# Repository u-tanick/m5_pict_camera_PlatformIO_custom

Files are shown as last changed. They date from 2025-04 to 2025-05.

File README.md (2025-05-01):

# m5_pict_camera_PlatformIO_custom

Yuikawa-Akiraさんが[こちらで公開されているPict_Cameraのコード](https://gist.github.com/Yuikawa-Akira)をもとに、PlatformIO化＋自分の手持ちの機器に合わせた改修＋機能追加を行ったものです。

オリジナルのピクセルアート風の画像を保存する機能に加えて、以下の機能を追加実装しています。

- スクロールユニットによるカメラシャッター機能
  - オリジナルはエンコーダーユニットですが、スクロールユニットに変更しています。
- デジタルズーム機能（1.0～4.0倍）
  - カメラ撮影モードの際に、スクロールユニットを右に回転させるとズームします。
  - ズームした状態でスクロールユニットを押すとズームされた状態の画像でピクセルアート画像が保存されます。
- プレビューモード機能
  - カメラモードで左にスクロールすると画面が「Press Button Previre Mode」と表示されるのでそこでスクロールユニットを押すと撮像した画像をLCDディスプレイでプレビューする機能に切り替わります。
  - プレビューモード時に再度スクロールユニットを押すとカメラモードに戻ります。
  - プレビューモードに切り替わる際は、その時点の画像のリストを作成するため数秒の処理待ちが発生します。
  - また、画像のIDは電源のON/OFFでリセットされるため必ずしも新しいもの順といった規則性のある順序にはなっていません。

以下の機器をセットする想定で作成したカメラケースのデータを、stlフォルダに格納しています。

- [AtomS3Rカメラ](https://www.switch-science.com/products/9916)
- [ATOMIC TFカードリーダー](https://www.switch-science.com/products/9423)
- [LCDディスプレイユニット](https://www.switch-science.com/products/7358)
- [スクロールユニット](https://www.switch-science.com/products/9917)
- [拡張ハブユニット](https://www.switch-science.com/products/5696)
- [GROVE互換ケーブル 10cm](https://www.switch-science.com/products/5213)
  - 1本
- [GROVE互換ケーブル 5cm](https://www.switch-science.com/products/8664)
  - 2本
- [SDカード Class10 16GB以下](https://www.yodobashi.com/?spcs=Specvaluecode_500000301004005003,500000301004005005_0001_0000000025_0000033030&spcs=Specvaluecode_500000301004005003,500000301004005005_0001_0000000338_0000009621&word=SD%E3%82%AB%E3%83%BC%E3%83%89+16GB)
- [レゴテクニック　ピン](https://www.amazon.co.jp/dp/B07B9R4J55/)
  - 1本
- [モバイルバッテリー：cheero canvas 3200mAh](https://www.amazon.co.jp/dp/B0BPC5BPVK/)
- [USB Type-Cケーブル 10cm以下](https://www.amazon.co.jp/dp/B0DJ85RLDN/)
  - 両端 Type-C のものはなぜか通電しなかったので、Type-A - Type-C を使用しました。
  - あまり10cm以下の商品は少ないのですが、購入の際はご注意（自己責任）ください。
- [100均で売っている 木ネジ（12mm*3mm）](https://jp.daisonet.com/products/4991203166913)

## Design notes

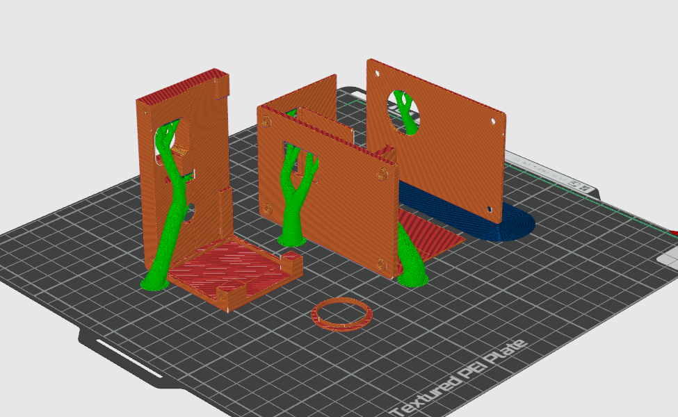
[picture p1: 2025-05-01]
stl/camera-case-set-slice.png

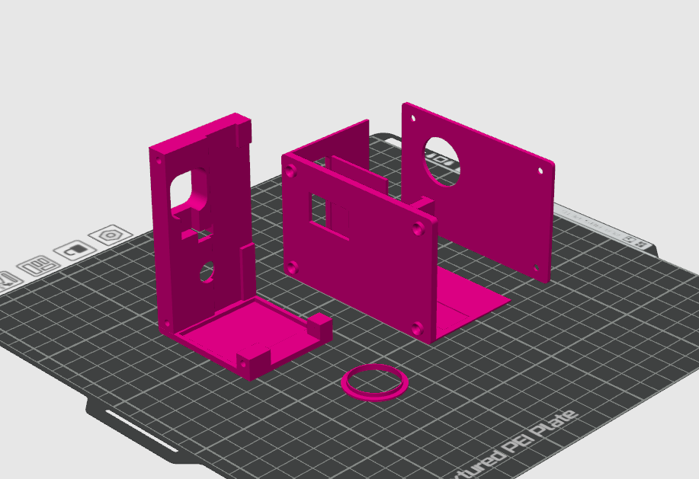
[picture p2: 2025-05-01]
stl/camera-case-set.png

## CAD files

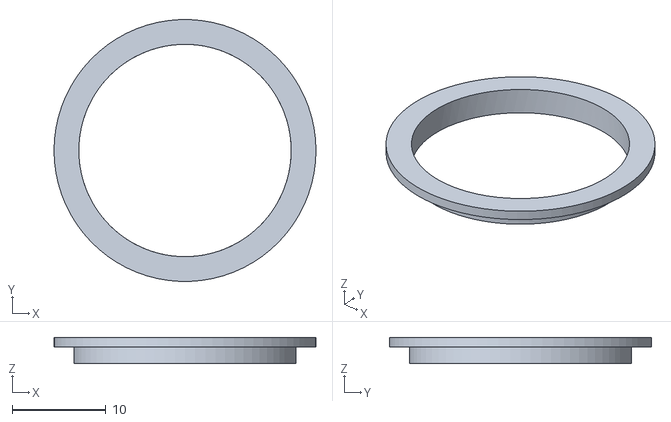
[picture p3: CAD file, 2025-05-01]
stl/camera-case-04_ring v67.stl
28.0 x 28.0 x 2.80

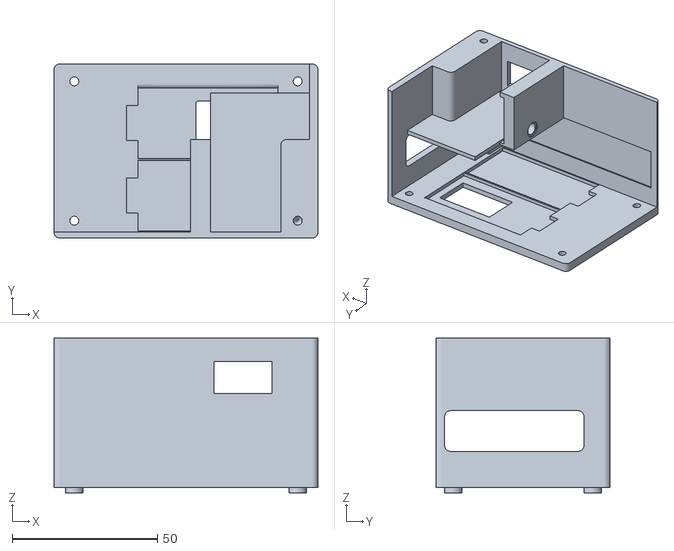
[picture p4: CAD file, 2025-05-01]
stl/camera-case-02_back_bottom_leftpanel v70.stl
91.0 x 60.0 x 53.3

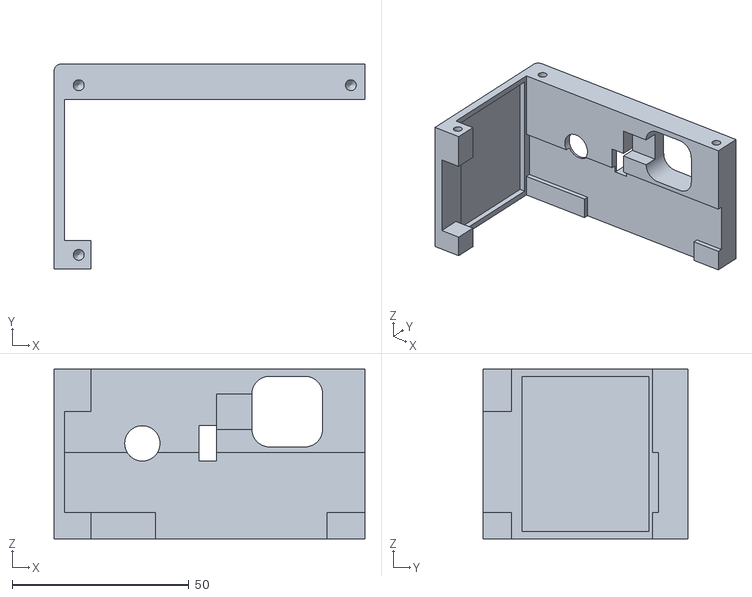
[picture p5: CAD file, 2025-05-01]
stl/camera-case-01_top_rightpanel v71.stl
88.0 x 58.0 x 48.0

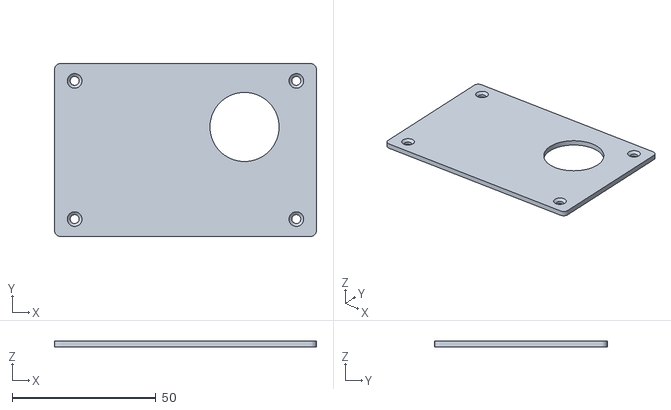
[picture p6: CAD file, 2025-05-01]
stl/camera-case-03_frontpanel v67.stl
91.0 x 60.0 x 2.00

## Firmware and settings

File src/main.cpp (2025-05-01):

#include <M5Unified.h>
#include "M5UnitScroll.h"
#include <M5UnitLCD.h>
#include <esp_camera.h>
#include <SPI.h>
#include <SD.h>
#include <vector>

// ----------------------------------------------------
// Grove PIN
#define PIN_SCL 1
#define PIN_SDA 2

// ----------------------------------------------------
// ユニットスクロール関連の変数・定数
M5UnitScroll scroll;
bool PRESSED_FLG = false;

// ----------------------------------------------------
// UnitLCD関連の変数・定数
M5UnitLCD display;
M5Canvas canvas(&display);

// ----------------------------------------------------
// 最大8色のカラーパレット デフォルト関連の変数・定数
int maxPaletteSize = 8;
uint32_t ColorPalettes[8][8] = {
    {// パレット0 slso8
     0x0D2B45, 0x203C56, 0x544E68, 0x8D697A, 0xD08159, 0xFFAA5E, 0xFFD4A3, 0xFFECD6},
    {// パレット1 都市伝説解体センター風
     0x000000, 0x000B22, 0x112B43, 0x437290, 0x437290, 0xE0D8D1, 0xE0D8D1, 0xFFFFFF},
    {// パレット2 ファミレスを享受せよ風
     0x010101, 0x33669F, 0x33669F, 0x33669F, 0x498DB7, 0x498DB7, 0xFBE379, 0xFBE379},
    {// パレット3 gothic-bit
     0x0E0E12, 0x1A1A24, 0x333346, 0x535373, 0x8080A4, 0xA6A6BF, 0xC1C1D2, 0xE6E6EC},
    {// パレット4 noire-truth
     0x1E1C32, 0x1E1C32, 0x1E1C32, 0x1E1C32, 0xC6BAAC, 0xC6BAAC, 0xC6BAAC, 0xC6BAAC},
    {// パレット5 2BIT DEMIBOY
     0x252525, 0x252525, 0x4B564D, 0x4B564D, 0x9AA57C, 0x9AA57C, 0xE0E9C4, 0xE0E9C4},
    {// パレット6 deep-maze
     0x001D2A, 0x085562, 0x009A98, 0x00BE91, 0x38D88E, 0x9AF089, 0xF2FF66, 0xF2FF66},
    {// パレット7 night-rain
     0x000000, 0x012036, 0x3A7BAA, 0x7D8FAE, 0xA1B4C1, 0xF0B9B9, 0xFFD159, 0xFFFFFF},
};

// カラーパレット値確認(デバッグ用、シリアル出力のみ)
void checkPalettes()
{
  for (int pi = 0; pi < maxPaletteSize; ++pi)
  {
    Serial.printf("%X,%X,%X,%X,%X,%X,%X,%X\n", ColorPalettes[pi][0], ColorPalettes[pi][1], ColorPalettes[pi][2], ColorPalettes[pi][3], ColorPalettes[pi][4], ColorPalettes[pi][5], ColorPalettes[pi][6], ColorPalettes[pi][7]);
  }
}

// ----------------------------------------------------
// カメラ・PSRAM関連の変数・定数
#define POWER_GPIO_NUM 18
camera_fb_t *fb;
camera_config_t camera_config = {
    .pin_pwdn = -1,
    .pin_reset = -1,
    .pin_xclk = 21,
    .pin_sscb_sda = 12,
    .pin_sscb_scl = 9,
    .pin_d7 = 13,
    .pin_d6 = 11,
    .pin_d5 = 17,
    .pin_d4 = 4,
    .pin_d3 = 48,
    .pin_d2 = 46,
    .pin_d1 = 42,
    .pin_d0 = 3,

    .pin_vsync = 10,
    .pin_href = 14,
    .pin_pclk = 40,

    .xclk_freq_hz = 20000000,
    .ledc_timer = LEDC_TIMER_0,
    .ledc_channel = LEDC_CHANNEL_0,

    .pixel_format = PIXFORMAT_RGB565,
    .frame_size = FRAMESIZE_HQVGA,
    // FRAMESIZE_96X96,    // 96x96
    // FRAMESIZE_QQVGA,    // 160x120
    // FRAMESIZE_QCIF,     // 176x144
    // FRAMESIZE_HQVGA,    // 240x176
    // FRAMESIZE_240X240,  // 240x240
    // FRAMESIZE_QVGA,     // 320x240

    .jpeg_quality = 0,
    .fb_count = 2,
    .fb_location = CAMERA_FB_IN_PSRAM,
    .grab_mode = CAMERA_GRAB_LATEST,
    .sccb_i2c_port = 0,
};

// ----------------------------------------------------
// カメラ画像保存関連の変数・定数
char filename_bmp[64];         // SDカード保存ファイル名
int filecounter = 1;           // ファイルカウンターは電源を入れるたびにリセットされる　極稀にファイル名が被るかも
int selectedPalettelndex = -1; // 選択したパレットの番号（0-8：個別指定, -1：未指定（デフォルト））
uint8_t graydata[240 * 176];   // 輝度情報保存
uint32_t btnOnTime = 0;        // 外部ボタン（スクロールユニットなど）を操作した時間
float zoomRate = 1.0;          // ズーム倍率（1.0倍スタート）
camera_fb_t processed_fb;      // 拡大後用のフレーム構造体
uint8_t *processed_buf = NULL; // 加工済みのバッファ本体（free対象）

#define HQVGA_WIDTH 240
#define HQVGA_HEIGHT 176
#define PIXEL_SIZE 2 // RGB565

// ----------------------------------------------------
// ファイル名リスト作成関連の変数・定数
constexpr size_t MAX_FILENAME_LEN = 128;           // ファイル名の最大長（先頭に/を付けるのでちょっと余裕もたせる）
constexpr size_t MAX_FILES = 1500;                 // 想定する最大bmpファイル数 1750あたりで確保領域がバッファオーバーフロー
size_t MAX_FILE_NUMBER = 0;                        // 実際のファイル数
char fileNameStorage[MAX_FILES][MAX_FILENAME_LEN]; // ファイル名バッファ
std::vector<char *> bmpFileNames;                  // bmpファイル名だけを入れるリスト

// ----------------------------------------------------
// 汎用プリント関数

// 文字列用
void printlnStr(String str)
{
  display.println(str);
  Serial.println(str);
}
// Int用
void printlnInt(int16_t i)
{
  display.println(i);
  Serial.println(i);
}
// LCD描画用
void displayStr(String str)
{
  display.drawCenterString(str, 120, 60);
  Serial.println(str);
}

// ----------------------------------------------------
// SDカード関連の関数

// SDカードにカラーパレットファイルがあれば読み込むための関数
// src/フォルダにサンプル(ColorPallettes.txt)があるため、使用する場合は事前にSDカードに保存しておく
// サンプルの設定は uint32_t ColorPalettes[8][8] の定義と同様のため、色合いを変えて保存したい場合にファイルを使用する想定
bool loadPaletteFromSD(String filename)
{
  // SDカード内のファイルからカラーパレットを読み込む
  File file = SD.open(filename, FILE_READ);
  if (!file)
  {
    // ファイルオープン失敗
    return false;
  }

  // 8パターンのカラーパレットを順に読み込みColorPalettes[paletteIndex][colorCode]にセット
  int paletteIndex = 0;
  while (file.available() && paletteIndex < maxPaletteSize)
  {
    String line = file.readStringUntil('\n');
    line.trim();

    if (line.startsWith("#") || line.length() == 0)
    {
      // コメント行（#始まり）・空行はスキップ
      continue;
    }

    uint32_t colors[8];
    int colorCount = 0;
    int lastIndex = 0;

    while (colorCount < 8)
    {
      int commaIndex = line.indexOf(',', lastIndex);
      String colorStr;

      if (commaIndex == -1)
      {
        colorStr = line.substring(lastIndex);
      }
      else
      {
        colorStr = line.substring(lastIndex, commaIndex);
        lastIndex = commaIndex + 1;
      }

      colorStr.trim();
      char hexBuffer[16];
      colorStr.toCharArray(hexBuffer, sizeof(hexBuffer));
      uint32_t color = strtoul(hexBuffer, NULL, 0); // ← base = 0 により0x(16進)を自動判別

      colors[colorCount++] = color;

      if (commaIndex == -1)
      {
        break;
      }
    }
    if (colorCount != 8)
    {
      // カラーパレット定義が8色ではない不正な色数として読み込み失敗とする
      file.close();
      return false;
    }

    for (int i = 0; i < 8; ++i)
    {
      ColorPalettes[paletteIndex][i] = colors[i];
    }

    paletteIndex++;
  }
  file.close();

  // カラーパレット定義の上書き成功またはデフォルト定義のままの場合trueを返す
  return true;
}

// 起動時のファイルの読み書きテスト用の関数
bool testReadWriteSD()
{
  // ファイル読み書きテスト用ファイル名
  const char *filename = "/_writeTest.txt";

  // ファイル作成と書き込み
  File writeFile = SD.open(filename, FILE_WRITE);
  if (writeFile)
  {
    writeFile.println("test");
    writeFile.close();
    Serial.println("ファイルに書き込みました。");
  }
  else
  {
    Serial.println("ファイルの作成または書き込みに失敗しました。");
    return false;
  }

  // ファイル読み込み
  File readFile = SD.open(filename);
  if (readFile)
  {
    String content = readFile.readStringUntil('\n');
    content.trim();
    Serial.print("読み込んだ文字列: ");
    Serial.println(content);
    readFile.close();

    // 読み込んだ内容が "test" ならファイルの読み書き成功としてテスト用ファイルも削除
    if (content == "test")
    {
      if (SD.remove(filename))
      {
        Serial.println("ファイルを削除しました。");
      }
      else
      {
        Serial.println("ファイルの削除に失敗しました。");
        return false;
      }
    }
    else
    {
      Serial.println("書き込んだ内容と読み込んだ内容が一致しないため、ファイルを削除しません。");
      return false;
    }
  }
  else
  {
    Serial.println("ファイルの読み込みに失敗しました。");
    return false;
  }

  // 削除確認
  if (!SD.exists(filename))
  {
    Serial.println("ファイルが正常に削除されています。");
  }
  else
  {
    Serial.println("ファイルがまだ存在しています。");
    return false;
  }

  return true;
}

// ----------------------------------------------------
// カメラ・PSRAM関連

// カメラ初期設定用関数
bool CameraBegin()
{
  esp_err_t err = esp_camera_init(&camera_config);
  if (err != ESP_OK)
  {
    printlnStr(" Error Code");
    printlnInt(err);
    return false;
  }

  // カメラ追加設定
  sensor_t *s = esp_camera_sensor_get();

  // AtomS3R Cam のときはこちら
  s->set_hmirror(s, 1); // 左右反転 0無効 1有効
  s->set_vflip(s, 1);   // 上下反転 0無効 1有効

  // AtomS3R M12 のときはこちら
  // s->set_lenc(s, 1);     // レンズ補正？ 効いてるか微妙
  // s->set_hmirror(s, 1);  // 左右反転 0無効 1有効
  // s->set_vflip(s, 0);    // 上下反転 0無効 1有効

  return true;
}

// カメラ画像読み込み用関数
bool CameraGet()
{
  fb = esp_camera_fb_get();
  if (!fb)
  {
    return false;
  }
  return true;
}

// カメラのフレームバッファ開放用関数
bool CameraFree()
{
  if (fb)
  {
    esp_camera_fb_return(fb);
    return true;
  }
  return false;
}

// ----------------------------------------------------
// カメラ画像保存関連

// ズーム倍率に合わせた画像のリサイズおよび切り出し
uint8_t *scaleAndCrop_RGB565()
{

  const uint8_t *fb_buf = fb->buf;

  // リサイズスケール
  const int scaled_w = (int)(HQVGA_WIDTH * zoomRate);
  const int scaled_h = (int)(HQVGA_HEIGHT * zoomRate);
  // 切り出し座標
  const int crop_x = (scaled_w - HQVGA_WIDTH) / 2;
  const int crop_y = (scaled_h - HQVGA_HEIGHT) / 2;

  uint8_t *result = (uint8_t *)malloc(HQVGA_WIDTH * HQVGA_HEIGHT * PIXEL_SIZE);
  if (!result)
    return nullptr;

  for (int y = 0; y < HQVGA_HEIGHT; y++)
  {
    for (int x = 0; x < HQVGA_WIDTH; x++)
    {
      int sx = (int)((x + crop_x) / zoomRate);
      int sy = (int)((y + crop_y) / zoomRate);

      // 範囲チェック
      if (sx >= HQVGA_WIDTH)
        sx = HQVGA_WIDTH - 1;
      if (sy >= HQVGA_HEIGHT)
        sy = HQVGA_HEIGHT - 1;

      int src_idx = (sy * HQVGA_WIDTH + sx) * PIXEL_SIZE;
      int dst_idx = (y * HQVGA_WIDTH + x) * PIXEL_SIZE;

      result[dst_idx] = fb_buf[src_idx];
      result[dst_idx + 1] = fb_buf[src_idx + 1];
    }
  }

  return result;
}

// カメラが撮像したオリジナル画像を保存
bool saveToSD_OriginalBMP()
{
  sprintf(filename_bmp, "/%010d_%04d_Original.bmp", btnOnTime, filecounter);
  File file_bmp = SD.open(filename_bmp, "w");
  if (file_bmp)
  {
    uint8_t *out_bmp = NULL;
    size_t out_bmp_len = 0;

    camera_fb_t *raw_fb = fb;

    if (zoomRate > 1.0)
    {
      // 1.0倍よりもズームしている場合
      // 画像データを拡大し、一定のサイズに切り出したデータに変換
      processed_buf = scaleAndCrop_RGB565();
      if (!processed_buf)
      {
        esp_camera_fb_return(raw_fb);
        file_bmp.close();
        return false;
      }

      processed_fb.buf = processed_buf;
      processed_fb.len = HQVGA_WIDTH * HQVGA_HEIGHT * PIXEL_SIZE;
      processed_fb.width = HQVGA_WIDTH;
      processed_fb.height = HQVGA_HEIGHT;
      processed_fb.format = PIXFORMAT_RGB565;
      fb = &processed_fb;
      esp_camera_fb_return(raw_fb);
    }
    else
    {
      fb = raw_fb;
    }
    frame2bmp(fb, &out_bmp, &out_bmp_len);
    file_bmp.write(out_bmp, out_bmp_len);
    file_bmp.close();
    free(out_bmp);
  }
  else
  {
    // ファイルの作成・オープンに失敗した場合falseを返す
    return false;
  }
  return true;
}

// LCDディスプレイに表示された画像を保存
bool saveToSD_DisplayBMP()
{
  sprintf(filename_bmp, "/%010d_%04d_LCD.bmp", btnOnTime, filecounter);
  File file_bmp = SD.open(filename_bmp, "w");
  if (file_bmp)
  {
    int width = display.width();
    int height = display.height();
    int rowSize = (3 * width + 3) & ~3;

    lgfx::bitmap_header_t bmpheader;
    bmpheader.bfType = 0x4D42;
    bmpheader.bfSize = rowSize * height + sizeof(bmpheader);
    bmpheader.bfOffBits = sizeof(bmpheader);
    bmpheader.biSize = 40;
    bmpheader.biWidth = width;
    bmpheader.biHeight = height;
    bmpheader.biPlanes = 1;
    bmpheader.biBitCount = 24;
    bmpheader.biCompression = 0;
    bmpheader.biSizeImage = 0;
    bmpheader.biXPelsPerMeter = 2835;
    bmpheader.biYPelsPerMeter = 2835;
    bmpheader.biClrUsed = 0;
    bmpheader.biClrImportant = 0;

    file_bmp.write((std::uint8_t *)&bmpheader, sizeof(bmpheader));
    std::uint8_t buffer[rowSize];
    memset(&buffer[rowSize - 4], 0, 4);
    for (int y = height - 1; y >= 0; y--)
    {
      display.readRect(0, y, width, 1, (lgfx::rgb888_t *)buffer);
      file_bmp.write(buffer, rowSize);
    }
    file_bmp.close();
  }
  else
  {
    // ファイルの作成・オープンに失敗した場合falseを返す
    return false;
  }
  return true;
}

// オリジナルの画像をカラーパレットの色調に変換した画像を保存
bool saveToSD_ConvertBMP()
{
  int max_index;
  int palettelndex = 0;
  if (selectedPalettelndex == -1)
  {
    // 全カラーパレット保存モード（デフォルト）
    max_index = maxPaletteSize;
  }
  else
  {
    // 指定パレットのみ保存モード
    max_index = 1;
    palettelndex = selectedPalettelndex;
  }

  for (int i = 0; i < max_index; i++)
  {

    if (selectedPalettelndex == -1)
    {
      palettelndex = i;
    }

    sprintf(filename_bmp, "/%010d_%04d_palette%01d.bmp", btnOnTime, filecounter, i);
    File file_bmp = SD.open(filename_bmp, "w");
    if (file_bmp)
    {
      int width = fb->width;
      int height = fb->height;
      int rowSize = (3 * width + 3) & ~3;

      lgfx::bitmap_header_t bmpheader;
      bmpheader.bfType = 0x4D42;
      bmpheader.bfSize = rowSize * height + sizeof(bmpheader);
      bmpheader.bfOffBits = sizeof(bmpheader);
      bmpheader.biSize = 40;
      bmpheader.biWidth = width;
      bmpheader.biHeight = height;
      bmpheader.biPlanes = 1;
      bmpheader.biBitCount = 24;
      bmpheader.biCompression = 0;
      bmpheader.biSizeImage = 0;
      bmpheader.biXPelsPerMeter = 2835;
      bmpheader.biYPelsPerMeter = 2835;
      bmpheader.biClrUsed = 0;
      bmpheader.biClrImportant = 0;

      file_bmp.write((std::uint8_t *)&bmpheader, sizeof(bmpheader));
      std::uint8_t buffer[rowSize];
      memset(&buffer[rowSize - 4], 0, 4);
      for (int y = height - 1; y >= 0; y--)
      {
        for (int x = 0; x < width; x++)
        {

          // グレイデータを読み出す
          int i_gray = y * width + x;
          uint8_t gray = graydata[i_gray];

          // カラーパレットから色を取得
          uint32_t newColor = ColorPalettes[palettelndex][gray];
          uint8_t r = (newColor >> 16) & 0xFF;
          uint8_t g = (newColor >> 8) & 0xFF;
          uint8_t b = newColor & 0xFF;

          // バッファに書き込み BGRの順になる
          int i_buffer = x * 3;
          buffer[i_buffer] = b;
          buffer[i_buffer + 1] = g;
          buffer[i_buffer + 2] = r;
        }
        file_bmp.write(buffer, rowSize);
      }
      file_bmp.close();
    }
    else
    {
      // ファイルの作成・オープンに失敗した場合falseを返す(処理を中断)
      return false;
    }
  }
  return true;
}

// 色調変更用の輝度情報保存データ作成
void saveGraylevel_fb()
{
  uint8_t *fb_data = fb->buf;
  int width = fb->width;
  int height = fb->height;
  int i = 0;

  for (int y = 0; y < height; y++)
  {
    for (int x = 0; x < (width * 2); x = x + 2)
    {

      // 各ピクセルの色を取得
      uint32_t rgb565Color = (fb_data[y * width * 2 + x] << 8) | fb_data[y * width * 2 + x + 1];

      // RGB565からRGB888へ変換
      uint32_t rgb888Color = canvas.color16to24(rgb565Color);
      uint8_t r = (rgb888Color >> 16) & 0xFF;
      uint8_t g = (rgb888Color >> 8) & 0xFF;
      uint8_t b = rgb888Color & 0xFF;

      // 輝度の計算 BT.709の係数を使用
      uint16_t luminance = (uint16_t)(0.2126 * r + 0.7152 * g + 0.0722 * b);

      // 輝度を16階調のグレースケールに変換
      uint8_t grayLevel = luminance / 32; // 256/32 = 8

      // 輝度情報を保存
      graydata[i] = grayLevel;
      i++;
    }
  }
}

// カメラ画像を切り出してズーム表示（LCD描画用）
void pushImageZoom(M5Canvas *canvas, int dst_x, int dst_y, int dst_w, int dst_h,
                   const uint16_t *src16, int src_w, int src_h,
                   int crop_x, int crop_y, int crop_w, int crop_h)
{
  const uint8_t *src = (const uint8_t *)src16;

  for (int y = 0; y < dst_h; ++y)
  {
    for (int x = 0; x < dst_w; ++x)
    {
      int src_x = crop_x + (x * crop_w) / dst_w;
      int src_y = crop_y + (y * crop_h) / dst_h;
      if (src_x >= 0 && src_x < src_w && src_y >= 0 && src_y < src_h)
      {
        int index = (src_y * src_w + src_x) * 2;
        uint16_t color565 = ((uint16_t)src[index] << 8) | src[index + 1];
        uint32_t color888 = canvas->color16to24(color565);
        canvas->drawPixel(dst_x + x, dst_y + y, color888);
      }
    }
  }
}
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
void loop()
{
  // 初回起動時のEncoderValueを必ず0にセット
  if (initLoop)
  {
    int16_t iv = 0;
    scroll.setEncoderValue(iv);
    initLoop = false;
  }

  newEncoderValue = scroll.getEncoderValue();
  int diff = newEncoderValue - lastEncoderValue;

  if (!previewMode)
  {

    Serial.println(newEncoderValue);

    // ========== 通常モード ==========
    if (newEncoderValue <= -1)
    {
      // EncoderValueが-1以下の場合の処理

      // -1よりも小さい場合は強制的に-1にリセット
      if (newEncoderValue < -1)
      {
        scroll.setEncoderValue(-1);
        newEncoderValue = -1;
      }
      // Change Preview Mode表示
      canvas.fillSprite(LIGHTGREY);
      canvas.setTextColor(BLACK);
      canvas.setTextSize(2.4);
      canvas.drawCenterString("Press Button", 120, 45);
      canvas.drawCenterString("Preview Mode", 120, 75);
      canvas.pushSprite(&display, 0, 0);

      // ボタン押したらプレビューモードに入る
      if (scroll.getButtonStatus())
      {

        Serial.println("Press button");

        canvas.fillSprite(PINK);
        canvas.setTextColor(BLACK);
        canvas.setTextSize(2.4);
        canvas.drawCenterString("Please Wait", 120, 30);
        canvas.setTextSize(2.0);
        canvas.drawCenterString("Preview Mode", 120, 60);
        canvas.drawCenterString("Getting Ready", 120, 85);
        canvas.pushSprite(&display, 0, 0);

        previewMode = true;
        // 念のため EncoderValue を -1 に設定
        scroll.setEncoderValue(-1);
        newEncoderValue = -1;

        // サムネイル画像ファイル名のリストを作成
        getAllBmpFileNames();

        delay(500);
      }
    }
    else
    {
      // EncoderValueが 0 以上の場合の処理

      canvas.setTextSize(1.8);

      // 40よりも大きい場合は強制的に40にリセット
      if (newEncoderValue > 40)
      {
        scroll.setEncoderValue(40);
        newEncoderValue = 40;
      }

      // 最大倍率 4.0 倍（EncoderValue = 40 を最大とする）
      if (diff != 0)
      {
        zoomRate += diff * 0.1;
        if (zoomRate < 1.0)
          zoomRate = 1.0;
        if (zoomRate > 4.0)
          zoomRate = 4.0;
        Serial.printf("ZoomRate: %.1f\n", zoomRate);
      }

      if (scroll.getButtonStatus())
      {
        // カメラ画像の保存
        btnOnTime = millis();
        CameraGet();
        SD.end(); // 念のため一旦END
        delay(100);
        SD.begin(15, SPI, 80000000); // 保存失敗するときは速度を下げる

// LCDディスプレイ表示画像も保存する場合は SAVE_LCD_IMAGE を有効化する
// # define SAVE_LCD_IMAGE
#ifdef SAVE_LCD_IMAGE
        // LCDディスプレイに表示された画像を保存
        // カメラが撮像した画像を保存
        if (saveToSD_OriginalBMP() && saveToSD_DisplayBMP())
        {
#else
        // カメラが撮像した画像を保存
        if (saveToSD_OriginalBMP())
        {
#endif
          printlnStr(" Image Saving...");
          delay(100);
        }
        else
        {
          printlnStr(" Image Save Failed !");
          delay(100);
        }

        // 輝度情報の保存
        saveGraylevel_fb();

        // カラーパレットの色調に変換した画像を保存
        if (saveToSD_ConvertBMP())
        {
          printlnStr(" Pict Converting...");
          delay(1500);
        }
        else
        {
          printlnStr(" Convert Failed !");
          delay(1000);
        }

        CameraFree();
        SD.end();
        printlnStr(" Save Complete !!");
        printlnStr(" ");
        delay(2500);
        filecounter++;
      }

      // カメラからフレームを取得してLCDに表示
      if (CameraGet())
      {
        int src_w = fb->width;
        int src_h = fb->height;
        int crop_w = src_w / zoomRate;
        int crop_h = src_h / zoomRate;
        int crop_x = (src_w - crop_w) / 2;
        int crop_y = (src_h - crop_h) / 2;

        canvas.fillSprite(0);
        pushImageZoom(&canvas, 0, -16, 240, 176, (uint16_t *)fb->buf, src_w, src_h, crop_x, crop_y, crop_w, crop_h);
        canvas.pushSprite(&display, 0, 0);
        CameraFree();
      }
    }
  }
  else
  {
    // ========== プレビューモード ==========
    Serial.println("Preview Mode");
    delay(200);

    // スクロールの値によって処理を分岐
    if (newEncoderValue <= -1)
    {
      // EncoderValue が -1 の場合は "Preview Mode" を表示
      scroll.setEncoderValue(-1);
      newEncoderValue = -1;
      canvas.fillSprite(SKYBLUE);
      canvas.setTextColor(WHITE);
      canvas.setTextSize(2.6);
      canvas.drawCenterString("Preview Mode", 120, 20);
      canvas.setTextSize(2.0);
      canvas.drawCenterString("<- Scroll Image ->", 120, 55);
      canvas.drawCenterString("Press Button", 120, 85);
      canvas.drawCenterString("Return Camera Mode", 120, 105);
      canvas.pushSprite(&display, 0, 0);
    }
    else
    {
      // -1以外の場合は、ファイルリストに従って画像を表示する
      // ファイルリストが空ならエラーメッセージ表示
      if (bmpFileNames.empty())
      {
        canvas.fillSprite(RED);
        canvas.setTextColor(WHITE);
        canvas.setTextSize(2.0);
        canvas.drawCenterString("No BMP files found", 120, 60);
        canvas.pushSprite(&display, 0, 0);
      }
      else
      {
        if (newEncoderValue > MAX_FILE_NUMBER)
        {
          // EncoderValueの値はファイル数の最大を上限とする
          canvas.fillSprite(MAGENTA);
          canvas.setTextColor(WHITE);
          canvas.setTextSize(2.0);
          canvas.drawCenterString("Preview File End", 120, 60);
          canvas.pushSprite(&display, 0, 0);
          delay(2000);

          newEncoderValue = MAX_FILE_NUMBER;
          scroll.setEncoderValue(newEncoderValue);
        }
        else
        {
          // 現在のEncoderValueから表示すべきインデックスを決める
          int fileIndex = bmpFileNames.size() - 1 - newEncoderValue; // 降順

          // 範囲外にならないように補正
          if (fileIndex < 0)
            fileIndex = 0;
          if (fileIndex >= bmpFileNames.size())
            fileIndex = bmpFileNames.size() - 1;

          Serial.printf("Display file: %s\n", bmpFileNames[fileIndex]);

          // 画像をロードして表示
          canvas.fillSprite(BLACK);
          canvas.setTextColor(WHITE);
          canvas.setTextSize(1.4);

          SD.begin(15, SPI, 80000000);

          File bmpFile = SD.open(bmpFileNames[fileIndex]);
          if (bmpFile)
          {
            canvas.drawBmp(&bmpFile, 0, 0);
            bmpFile.close();
          }
          else
          {
            canvas.drawCenterString("Failed to load", 120, 60);
          }

          String str = String(MAX_FILE_NUMBER - fileIndex) + " / " + String(MAX_FILE_NUMBER);
          canvas.fillSmoothRoundRect(155, 8, 75, 15, 5, BLACK);
          canvas.drawRightString(str, 230, 10);
          canvas.pushSprite(&display, 0, 0);
        }
      }
    }

    if (scroll.getButtonStatus())
    {
      // プレビューモードでスクロールユニットのボタンが押されたら無条件で通常モードに戻る
      previewMode = false;
      scroll.setEncoderValue(-1);
      SD.end();
      delay(500);
    }
  }

  lastEncoderValue = newEncoderValue;
  delay(1);
}

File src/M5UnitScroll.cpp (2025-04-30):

/*
 * SPDX-FileCopyrightText: 2024 M5Stack Technology CO LTD
 *
 * SPDX-License-Identifier: MIT
 */
#include "M5UnitScroll.h"

/*! @brief Initialize the Scroll. */
bool M5UnitScroll::begin(TwoWire *wire, uint8_t addr, uint8_t sda, uint8_t scl, uint32_t speed) {
    _wire  = wire;
    _addr  = addr;
    _sda   = sda;
    _scl   = scl;
    _speed = speed;
    _wire->begin(_sda, _scl);
    _wire->setClock(_speed);
    delay(10);
    _wire->beginTransmission(_addr);
    uint8_t error = _wire->endTransmission();
    if (error == 0) {
        return true;
    } else {
        return false;
    }
}

/*! @brief Write a certain length of data to the specified register address. */
void M5UnitScroll::writeBytes(uint8_t addr, uint8_t reg, uint8_t *buffer, uint8_t length) {
    _wire->beginTransmission(addr);
    _wire->write(reg);
    for (int i = 0; i < length; i++) {
        _wire->write(*(buffer + i));
    }
    _wire->endTransmission();
}

/*! @brief Read a certain length of data to the specified register address. */
void M5UnitScroll::readBytes(uint8_t addr, uint8_t reg, uint8_t *buffer, uint8_t length) {
    uint8_t index = 0;
    _wire->beginTransmission(addr);
    _wire->write(reg);
    _wire->endTransmission(false);
    _wire->requestFrom(addr, length);
    for (int i = 0; i < length; i++) {
        buffer[index++] = _wire->read();
    }
}

/*! @brief Read the encoder value.
    @return The value of the encoder that was read */
int16_t M5UnitScroll::getEncoderValue(void) {
    int16_t value = 0;

    readBytes(_addr, ENCODER_REG, (uint8_t *)&value, 2);
    return value;
}

/*! @brief Read the encoder inc value.
    @return The value of the encoder that was read */
int16_t M5UnitScroll::getIncEncoderValue(void) {
    int16_t value = 0;

    readBytes(_addr, INC_ENCODER_REG, (uint8_t *)&value, 2);
    return value;
}

/*! @brief Get the current status of the rotary encoder button.
    @return true if the button was pressed, otherwise false. */
bool M5UnitScroll::getButtonStatus(void) {
    uint8_t data;
    readBytes(_addr, BUTTON_REG, &data, 1);
    return data == 0x00;
}

/*! @brief Set the color of the LED (HEX). */
void M5UnitScroll::setLEDColor(uint32_t color, uint8_t index) {
    uint8_t data[4];
    data[3] = color & 0xff;
    data[2] = (color >> 8) & 0xff;
    data[1] = (color >> 16) & 0xff;
    data[0] = index;
    writeBytes(_addr, RGB_LED_REG, data, 4);
}

/*! @brief Get the color of the LED (HEX).
    @return The value of the led that was read */
uint32_t M5UnitScroll::getLEDColor(void) {
    uint8_t data[4];
    uint32_t value = 0;

    readBytes(_addr, RGB_LED_REG, data, 4);
    value = (data[3] | (data[2] << 8) | (data[1] << 16));
    return value;
}

void M5UnitScroll::setEncoderValue(int16_t encoder) {
    writeBytes(_addr, ENCODER_REG, (uint8_t *)&encoder, 2);
}

void M5UnitScroll::resetEncoder(void) {
    uint8_t data = 1;
    writeBytes(_addr, 0x40, &data, 1);
}

/*! @brief Get the dev status.
    @return 1 if the dev working, otherwise 0.. */
bool M5UnitScroll::getDevStatus(void) {
    _wire->beginTransmission(_addr);
    if (_wire->endTransmission() == 0)
        return true;
    else
        return false;
}

uint8_t M5UnitScroll::getBootloaderVersion(void) {
    _wire->beginTransmission(_addr);
    _wire->write(BOOTLOADER_VERSION_REG);
    _wire->endTransmission(false);

    uint8_t RegValue;

    _wire->requestFrom(_addr, 1);
    RegValue = _wire->read();
    return RegValue;
}

uint8_t M5UnitScroll::getFirmwareVersion(void) {
    _wire->beginTransmission(_addr);
    _wire->write(FIRMWARE_VERSION_REG);
    _wire->endTransmission(false);

    uint8_t RegValue;

    _wire->requestFrom(_addr, 1);
    RegValue = _wire->read();
    return RegValue;
}

uint8_t M5UnitScroll::setI2CAddress(uint8_t addr) {
    uint8_t temp[2] = {0};

    temp[0] = I2C_ADDRESS_REG;

    _wire->beginTransmission(_addr);
    _wire->write(temp[0]);
    _wire->write(addr);
    _wire->endTransmission();
    _addr = addr;
    return _addr;
}

uint8_t M5UnitScroll::getI2CAddress(void) {
    uint8_t temp[2] = {0};

    temp[0] = I2C_ADDRESS_REG;

    _wire->beginTransmission(_addr);
    _wire->write(temp[0]);
    _wire->endTransmission(false);

    uint8_t RegValue;

    _wire->requestFrom(_addr, 1);
    RegValue = _wire->read();
    return RegValue;
}

void M5UnitScroll::jumpBootloader(void) {
    uint8_t value = 1;

    writeBytes(_addr, JUMP_TO_BOOTLOADER_REG, (uint8_t *)&value, 1);
}

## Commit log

2025-04-22 add stl folder
2025-04-30 UnitScrollバグ修正、暫定動作版main
2025-05-01 add stl, refactor main.cpp
    [camera-case-01_top_rightpanel v71.stl, camera-case-02_back_bottom_leftpanel v70.stl, camera-case-03_frontpanel v67.stl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]
